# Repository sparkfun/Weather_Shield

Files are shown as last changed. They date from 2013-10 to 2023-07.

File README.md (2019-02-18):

SparkFun Weather Shield
========================

SparkFun Weather Shield (https://www.sparkfun.com/products/13956)  

[*SparkFun Weather Shield (DEV-13956)*](https://www.sparkfun.com/products/13956)

Weather Shield is an Arduino shield that gathers relative humidity, barometric pressure, temperature, light intensity, as well as optional rain, wind direction, and wind speed (using optional [external weather gauges](https://www.sparkfun.com/products/8942)).

Repository Contents
------------------

* **/Firmware** - Example Arduino sketch to demostrate how to read from the various sensors.
* **/Fritzing** - Fritzing Example wiring images
* **/Hardware** - All the Eagle PCB design files (.brd, .sch).
* **/Production** - Test bed files and production panel files

Documentation
--------------
* **[Installing an Arduino Library Guide](https://learn.sparkfun.com/tutorials/installing-an-arduino-library)** - Basic information on how to install an Arduino library.
* **[MPL3115A2 Library](https://github.com/sparkfun/SparkFun_MPL3115A2_Breakout_Arduino_Library)** - MPL3115A2 library required for Weather Shield examples. 
* **[Si7021 Library](https://github.com/sparkfun/SparkFun_Si701_Breakout_Arduino_Library)** - Si7021 humidity sensor library required for Weather Shield examples. 
* **[Hookup Guide](https://learn.sparkfun.com/tutorials/arduino-weather-shield-hookup-guide-v12)** - Basic hookup guide for the Weather Shield v1.2.
* **[SparkFun Fritzing repo](https://github.com/sparkfun/Fritzing_Parts)** - Fritzing diagrams for SparkFun products.
* **[SparkFun 3D Model repo](https://github.com/sparkfun/3D_Models)** - 3D models of SparkFun products. 
* _**[HTU21D Library](https://github.com/sparkfun/SparkFun_HTU21D_Breakout_Arduino_Library)** - The HTU21D humidity sensor was used on DEV-12081 and prior versions of the Weather Shield so if you have an older version you may need this library to run the examples._

Product Versions
----------------
* [DEV-13956](https://www.sparkfun.com/products/13956)- V1.2 w/ Si7021
* _[DEV-12081 (Retired)](https://www.sparkfun.com/products/13956)- HTU21D_

Version History
---------------
* [v1.2](https://github.com/sparkfun/Weather_Shield/releases/tag/v1.2) - Latest Version
* [v1.1](https://github.com/sparkfun/Weather_Shield/releases/tag/v1.1) - Initial Release

License Information
-------------------

This product is _**open source**_! 

Please review the LICENSE.md file for license information. 

If you have any questions or concerns on licensing, please contact techsupport@sparkfun.com.

Distributed as-is; no warranty is given.

- Your friends at SparkFun.

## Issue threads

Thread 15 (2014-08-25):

Instantenous wind speed reported as 0 or NaN

chopsuei3, 2014-08-25:
I set up my Redboard and Weathershield, and attached my weather sensors via the RJ-11 jack.

I compiled and uploaded the code, and receive accurate temperature, humidity and pressure readings.
I also receive accurate wind direction readings.

But the wind speed (instantaneous) returns either 0 or NaN.

Here is the example serial monitor output when spinning the anemometer -

$,winddir=45,windspeedmph=nan,windgustmph=0.0,windgustdir=0,windspdmph_avg2m=0.0,winddir_avg2m=0,windgustmph_10m=0.0,windgustdir_10m=0,humidity=41.9,tempf=78.4,rainin=0.00,dailyrainin=0.00,pressure=100737.25,batt_lvl=4.42,light_lvl=0.30,#

$,winddir=45,windspeedmph=0.0,windgustmph=0.0,windgustdir=0,windspdmph_avg2m=0.0,winddir_avg2m=1,windgustmph_10m=0.0,windgustdir_10m=0,humidity=41.9,tempf=78.5,rainin=0.00,dailyrainin=0.00,pressure=100735.50,batt_lvl=4.42,light_lvl=0.28,#

I commented out lines 335 to 337 to try debugging a bit.
When I do this, the WindSpeed is printed twice, once as 0 and once as the correct speed.

$,winddir=225,windspeedmph=0.0,windgustmph=0.0,windgustdir=0,windspdmph_avg2m=0.9,winddir_avg2m=36,windgustmph_10m=12.1,windgustdir_10m=225,humidity=42.3,tempf=77.7,rainin=0.00,dailyrainin=0.00,pressure=100745.75,batt_lvl=4.42,light_lvl=0.33,#
Loop call:

Windspeed:5.48
Wind clicks:0
calcWeather call:

Windspeed:0.00
Wind clicks:0

$,winddir=225,windspeedmph=0.0,windgustmph=0.0,windgustdir=0,windspdmph_avg2m=1.0,winddir_avg2m=38,windgustmph_10m=12.1,windgustdir_10m=225,humidity=42.3,tempf=77.6,rainin=0.00,dailyrainin=0.00,pressure=100742.25,batt_lvl=4.42,light_lvl=0.30,#
Loop call:

Windspeed:4.53
Wind clicks:0
calcWeather call:

Windspeed:0.00
Wind clicks:0

Further research reveals that get_wind_speed() is called twice, once in the main loop and once within calcWeather().
I added a few debug readings, and I believe the correct WindSpeed is printed within the main loop.
For some reason, the get_wind_speed() called within calcWeather() returns 0.

Am I missing something obvious?

It seems like the problem is related to the averaging of wind speed values over time.

I used the code directly from here.

Please help, thanks.
Let me know if there are more questions.

Thanks!

TechRep, 2015-05-02:
I got the same problem, have you been able to figure out the issue?

nseidle, 2015-09-11:
It looks like javacasm found the error. See https://github.com/sparkfun/Weather_Shield/pull/17/files#diff-0 It requires the change of one line

     //Calc the wind speed and direction every second for 120 second to get 2 minute average
-    float currentSpeed = get_wind_speed();
+    float currentSpeed = windspeedmph;

However, I'm still not seeing windgustmph change. Very odd.

nseidle, 2015-09-11:
Hmm, I think I found it. calcWeather() was zeroing out the values when it shouldn't. This sketch: https://codebender.cc/sketch:116056 should be fixed now. I will update the repo shortly.

Closed 2015-09-11.

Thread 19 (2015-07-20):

Getting wrong data?

thelostscientist, 2015-07-20:
$,winddir=-1,windspeedmph=nan,windgustmph=0.0,windgustdir=0,windspdmph_avg2m=5.7,winddir_avg2m=-1,windgustmph_10m=6.2,windgustdir_10m=-1,humidity=998.0,tempf=-1766.2,rainin=7.78,dailyrainin=7.79,pressure=-999.00,batt_lvl=inf,light_lvl=nan,#

rjp663, 2015-11-01:
I'm seeing the same temperature error (tempf=-1766.2).  The error seems to occur after about 24hours of run time.  Did you ever find the root cause for this issue?

Thanks,
Rick

ClintonKeith, 2015-11-18:
I'm seeing the temperature sensor defaulting to this temperature as well.  Sometimes it happens within an hour of reset, sometimes days later.

amitpatel144, 2016-03-06:
I face this troubling issue too. Is your problem solved or not ? Wait for your reply Mr. thelostscientist.

ClintonKeith, 2016-03-06:
No response here.  So I installed a DHT22 and get the temp/humidity from that now.

amitpatel144, 2016-03-06:
And Sir what about pressure Sensor MPL3115A2? Is it working properly?

ClintonKeith, 2016-03-06:
It’s working.  It doesn’t seem too accurate, but that’s the nature of most inexpensive pressure sensors.

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

amitpatel144, 2016-03-07:
Thanks Clinton Keith Sir, for important suggestion. As per as datasheet MPL3115A2 is high accurate pressure sensor, but I doesn't believed it. I used it but I am not satisfied from it. Many times it’s given -999hPa, wrong data and temperature too. One of my friend suggest again about this sensor.  I was in dilemma that may be my sensor is not working properly .But actually it is the base problem of this sensor.  Nor you and I but also many people faced this problem .The sensor manufacturer said that it’s your connection problem or I2C problem. Same as happen in temperature and humidity sensor HTU21D.

Thanks for suggestion. Now I moved to Bosch Sensortec sensor BME280.

ClintonKeith, 2016-03-07:
Thanks Amit,

Please let us know how the BME280 works out.  I may have to follow your lead.

The data I get from the MPL (plot below), shows noise within the accuracy range from the datasheet, but the overall average disagrees with other sensors in the area.  I might try to install another sensor nearby to compare.

Clint

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

amitpatel144, 2016-03-08:
Thanks for your best wishes. I'll try on BME280 as soon as possible.

ClintonKeith, 2016-03-11:
Just a follow-up on the built in sensor.  It’s worse than I thought.  The three plots show three local weather station barometric sensors.  The bottom one is the mine (the built-in weather shield).  The pressure response is the opposite of the others!  I noticed this as a storm just moved through.  I expected pressure to be dropping.

I’ll bet there is a bug with the example code.

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

amitpatel144, 2016-03-12:
yes ; I agree with you . I think i should need run both sensor at a time. Then I can distinguish better results .
Sir, I think you already watched the comparison result. If not then please watched it.
link: http://wiki.paparazziuav.org/wiki/Baro_comparsion

amitpatel144, 2016-04-07:
Hello Sir, I purchase a new sensor named BME280. Its precision is 1 meter .I got better result then any other pressure sensor. I got a huge difference between reading of MPL3115A2 and BME280. The noise level is low than MPL3115A2. I got many better feedback on BME280. This support I2C and SPI.
I'll attach output soon. Thanks for your best wishes.

amitpatel144, 2016-04-07:
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

nseidle, 2016-06-10:
To address the original problem: a humidity of 998 means the humidity sensor failed to respond over I2C in a timely fashion (ie, not at all). Similary, -999 from the pressure sensor means it failed as well. There is most likely a problem with your I2C bus. If you're using the shield check the solder connection. If you're using a combination of breakout boards double check that the bus has 4.7k pull-up resistors on the SDA/SCL lines. Most of our breakout boards have these pull-ups installed but not all companies include them.

I've touched up the [hook-up tutorial](https://learn.sparkfun.com/tutorials/weather-shield-hookup-guide#example-firmware---basic) to include a new basic sketch. Please give this a try as it will specifically call out an error if I2C communication fails.

@rjp663 I have seen the tempf go negative when I pulled the shield from the board while it was powered up and running, and then re-inserted the shield after a few seconds. I attribute this failure mode to the pressure sensor not getting re-initialized correctly.

I've had a handful of these shields in the field for months at a time without sensors needing to be reset or power cycled. I will run a few-day test over the weekend and re-open the issue.

rjp663, 2016-06-11:
Nathen,

Thanks for your detailed analysis.  Due to the unreliability of the shield I've move my temp and pressure sensors off board utilizing a BME280. The weather shield at this point only provides pull-up resistors for the rain, wind speed and wind direction connections.  I've also rewritten much of the code.

I've spent my free time for this last year playing around with this weather station.  Sooner or later I've got to stop tweaking on it and move on to another project.

Rick

Sent from my iPad

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

amitpatel144, 2016-06-11:
Is anyone got solution of MPL3115A2 sensor on Adruino due board?

aleixq, 2018-04-09:
Sorry to make it alive again but I get correct results using https://github.com/mariocannistra/MPL3115A2 . Running the calibration previously to get the value gives correct results. Run barometer_calibration example to test it (if running this example a lot of time it ends giving -999, let it rest for a while after)

Here I paste snippets of the code that I run giving good values:
```
float barominMb = 0.0;
float city_meters_above_sea = 280.0; // HARDCODED ALTITUDE
void setup(void){
//Configure the pressure sensor
myPressure.setModeStandby();    // <-- this one starts a config sequence
myPressure.setModeBarometer();
myPressure.setOversampleRate(7);
myPressure.enableEventFlags();
myPressure.setModeActive();
myPressure.runCalibration(city_meters_above_sea);
}
...
void loop(){
pressure = myPressure.readPressure();
barominMb = getPressuremb(pressure, city_meters_above_sea);
}
...
float getPressuremb(float pressure, float currentElevation)
{
  float pressure_offset = pressure + myPressure.elevation_offset;

  // output is in Pa
  // 1 kPa = 10 hPa = 1000 Pa
  // 1 hPa = 100 Pascals = 1 mb
  pressure_offset = (pressure_offset / 100) ;   //  ... / 1000 * 10 ;
  return pressure_offset;
}

```

nseidle, 2018-04-18:
Please start a new issue with as much of a description of your issue as possible.

Closed 2016-06-10.

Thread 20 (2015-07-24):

Does it work with arduino YUN?

thelostscientist, 2015-07-24:

nseidle, 2016-06-10:
Yes it should. The Yun uses an ATmega32U4 as the co-processor. See the [schematic](https://www.arduino.cc/en/uploads/Main/arduino-Yun-schematic.pdf) for more information. The shield should plug in and be able to communicate with the 32U4 without issue. However, all our example code is written for the Uno and RedBoard so I'm not sure I can help with code for the Yun.

Closed 2016-06-10.

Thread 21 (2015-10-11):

Example includes don't match library file names

ClintonKeith, 2015-10-11:
When compiling the Weather Shield example, I noticed that the includes:
#include "MPL3115A2.h" //Pressure sensor
#include "HTU21D.h" //Humidity sensor

needed to be changed to
#include "SparkFunMPL3115A2.h" //Pressure sensor
#include "SparkFunHTU21D.h" //Humidity sensor

Not sure which is correct (lib names or includes)

ToniCorinne, 2015-10-13:
Sorry about that! We tried to get all the example code when updating the Arduino libraries for 1.6+. Those have been fixed in commit 6442113715a5fa2c2fe53822eba27b16542d7d89. Thanks for pointing that out.

Closed 2015-10-13.

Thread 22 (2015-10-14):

Memory optimizations

ClintonKeith, 2015-10-14:
I've integrated the weathershield with an Uno and Xbee using SoftSerial to communicate.  Including the Xbee and SoftSerial libraries was a challenge due to the SRAM memory useage of the example sketch.  I cleaned up a number of the memory usage problems and have others to go, but thought I'd raise the issue here for discussion before I create a pull request:
- Use flash memory whenever possible.  Convert all print strings by putting them into the F() macro.
- Reduce averaging array size.  E.g. wind averaging arrays are 120 ints in size.  They can be reduced in size, samples taken less frequently or "averages of averages" can be used.
- Use constants and defines instead of values.  "120", "199", "10" are used repeatedly throughout the code for array and iteration size.  Constants defined at the top would allow more control.

BTW: Really impressed with how quickly this shield, hardware and example came up and ran.  Good job.

ToniCorinne, 2015-10-14:
These all sounds like great improvements. Please do issue a pull request and we'll take a look at it. Even if it doesn't necessarily work for our examples, it's a great record to have out there for other users.

nseidle, 2016-06-10:
Hi ClintonKeith - Yes please! If you get a good sketch put together and would like to share we'd be happy to cross link. I just touched up the [hook-up guide](https://learn.sparkfun.com/tutorials/weather-shield-hookup-guide#example-firmware---basic) and created some additional, more basic sketches to get beginners up and running. If you see places to improve the basic, weather station, or GPS sketches please do so and shoot us a pull request.

If I ever touch-up my weather stations I'll use that moment to circle back and implement some of your suggestions as well. I just can't make changes to the core code without a full setup to test it on.

Closed 2016-06-10.

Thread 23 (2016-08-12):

Error in GPS Example Code for Longitude

bboyho, 2016-08-12:
Customer brought up an error in the SFE Forums [ https://forum.sparkfun.com/viewtopic.php?f=14&t=39246#p176148 ]. GPS example code [ https://github.com/sparkfun/Weather_Shield/blob/master/firmware/Weather_Shield_with_GPS/Weather_Shield_with_GPS.ino ] has an error in the code when printing the variable name with the variable. Instead of saying longitude=, the code says that the latitude is equal to the longitude's value on line 445:

    Serial.print(",lat=");
    Serial.print(gps.location.lat(), 6);
    Serial.print(",lat=");
    Serial.print(gps.location.lng(), 6);

It should probably say:

    Serial.print(",lat=");
    Serial.print(gps.location.lat(), 6);
    Serial.print(",lng=");
    Serial.print(gps.location.lng(), 6);

ToniCorinne, 2016-08-12:
@bboyho if you want to change the code file and submit a pull request, I can get that pulled in.

bboyho, 2016-08-12:
Yup, already on it @ToniCorinne . I had to file the issues first so customers can track down the issues. I have forked it and will send in a pull request with the corrections soon. =)

bboyho, 2016-08-12:
Issue fixed in forked commit => https://github.com/bboyho/Weather_Shield/commit/d09a0d830e3668e70adf77a1f900ca0f23c9663b

ToniCorinne, 2016-08-16:
Fixed - closing the issue.

Closed 2016-08-16.

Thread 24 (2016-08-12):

Error in Weather_Shield_Weather_Station.ino where "windspeedmph" reads "0.0"

bboyho, 2016-08-12:
There have been customers reporting that the variable "_windspeedmph_" is constantly reporting "0.0". This is an error in the code Weather_Shield_Weather_Station.ino [ https://github.com/sparkfun/Weather_Shield/blob/master/firmware/Weather_Shield_Weather_Station/Weather_Shield_Weather_Station.ino ].

Looking at the sequence of code, it appears that whoever originally wrote the code did not update the global variable _windspeedmph_ for the _printWeather()_ function. Line 226 was commented out in _calcWeather()_ because the function _get_wind_speed()_ was already called in the loop function. The value was saved in the local variable called _currentSpeed_ on line 178:

    //Calc the wind speed and direction every second for 120 second to get 2 minute average
    float currentSpeed = get_wind_speed();
    .
    .
    .

By saving the value from _currentSpeed_ to the global variable, the global variable _windspeedmph_ was able to update and display a value other than "0.0":

    //Calc the wind speed and direction every second for 120 second to get 2 minute average
    float currentSpeed = get_wind_speed();
    windspeedmph = currentSpeed;//update global variable for windspeed when using the printWeather() function
    .
    .
    .

**Verifying _windspeedmph_**

You can verify that the value is correct by uncommenting out lines 356-358 and removing "/*" and "*/":

    /* Serial.println();
    Serial.print("Windspeed:");
    Serial.println(windSpeed);*/

Keep in mind that the the value printed in _calcWeather()_ outputs to the nearest hundredth while _printWeather()_ outputs to the nearest tenth. This is due to the way _serial.print()_ is called [ https://www.arduino.cc/en/Serial/Print ] . The default has the Arduino print to two decimal places. In _printWeather()_, the code specifies printing to the one decimal place.

bboyho, 2016-08-12:
Issue fixed in forked commit => https://github.com/bboyho/Weather_Shield/commit/d09a0d830e3668e70adf77a1f900ca0f23c9663b

ToniCorinne, 2016-08-16:
Fixed - closing the issue.

Closed 2016-08-16.

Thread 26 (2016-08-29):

v12 checklist issues

ericorosel, 2016-08-29:
(1) Per the standard, it would be nice if the "STAT1" and "STAT2" nets had a bend in them so that the flag could come straight out from the net while reading horizontally.

(2) Most parts have no PROD_ID

(3) The design loaded with an old DRC, and running the a new DRC results in errors

(4) There are air-wires in the design

(5) BRD contains Proportional text

JoelEB, 2016-09-27:
1) Adding bends for flags
2) Updated all parts to latest and added PROD_IDs to parts without.
3) Check board against newest DRC
4) Air-wires have been fixed
5) Text on BRD and SCH has been changed to vector.

Closed 2016-09-27.

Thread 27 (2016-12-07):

Double Check v12

edspark, 2016-12-07:
1) Are any jumpers labeled clearly by their function and possible settings? [NO]
comment: The Jumper for the Pressure Interrupt is labeled nicely on the board, but not on the schematic.

2) Is the board dimension outline correct thickness? (0.008 inch) [NO]
comment: The top edge dimension lines are .01

3) Does it pass SparkFun DRC? [NO]
comment: No but we're cool. Same restrict issues as the Photon Weather Shield.

4) Does it pass DRC with top/bottom keepout layers on? [NO]
comment: It's cool.

5) Do all packages have NAME and VALUE? [NO]
comment: Nope, it's fine.

6) Is the polarity label outside of the package for visibility after part population? [NO]
comment: No but it's cool.

7) The labels on Diodes D8, D10, and D5 are missing.

Closed 2016-12-09.

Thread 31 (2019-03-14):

Weather shield not working on Arduino Uno WIFI Rev 2

skuske, 2019-03-14:
All examples work fine on an Arduino Uno, but **they are not working** on an Arduino Uno WIFI Rev 2 - a lot of errors are produced when I try to upload any of the examples:

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

tkeifer, 2019-05-03:
Any updates on this? I'm running into the same issues. (negative values on Temperature/Pressure and can't include the Si7021 library without running into the same compile errors above)

Example code from the Sparkfun MPL3115A2 library
`Pressure(Pa): -31265 Temp(f): -1766.20
Pressure(Pa): -31204 Temp(f): -1766.20
Pressure(Pa): -31148 Temp(f): -1766.20
Pressure(Pa): -31333 Temp(f): -1766.20
Pressure(Pa): -31325 Temp(f): -1766.20
Pressure(Pa): -31434 Temp(f): -1766.20`

This is the 3rd WIFI companion board I've used with no luck...

skuske, 2019-05-08:
I am wondering if anybody of sparkfun monitors the issues... I doubt they do. Bad service.

tkeifer, 2019-05-08:
I've had a little better luck over at their forums: https://forum.sparkfun.com/

...but yeah, it seems like the way they have this shield setup it only is really designed to work with their Photon boards. Pretty disappointed with them as well.

santaimpersonator, 2019-12-31:
@skuske Sorry, we have a lot of repos that we curate; not including our forums, product pages, hookup guides, and etc.

I am marking this a duplicate and closing this issue since it isn't related to the hardware and there is another issue already file for the library causing the compilation issue (see https://github.com/sparkfun/SparkFun_Si701_Breakout_Arduino_Library/issues/4). This is was my response regarding this issue:

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

Closed 2019-12-31.

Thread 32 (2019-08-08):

Commented line #234 prevents working with GPS in Weather_Shield_with_GPS_V12.ino

wittend, 2019-08-08:
The fact that line #234 is commented out at the end of loop() prevents firmwareWeather_Shield_with_GPS_V12.ino from reading GPS if attached.  This problem is present in both the repo code and the code embedded in the tutorial page "Arduino Weather Shield Hookup Guide V12".

Uncommenting this line seems to fix things, at least with the specified GPS.

santaimpersonator, 2024-02-29:
Closing, as this is no longer relavent to the new code implementation

Closed 2024-02-29.

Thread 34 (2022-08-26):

Getting wrong readings

vdenduluri, 2022-08-26:
Hi,

I connected the [weather shield](https://www.sparkfun.com/products/13956) to [sparkfun redboard plus](https://www.sparkfun.com/products/18158) and ran the example program "Weather_Shield_Basic_V12". I am getting incorrect readings.

Is there something that I should do first before executing the program or something wrong with hardware? Anyhelp would be appreciated.

Humidity = -5.81%, temp_h = -51.85F, Pressure = -999.00Pa, temp_p = -1766.20F, light_lvl = 2.14V, VinPin = 12.08V
Humidity = -5.81%, temp_h = -51.85F, Pressure = -999.00Pa, temp_p = -1766.20F, light_lvl = 2.19V, VinPin = 11.91V
Humidity = -5.81%, temp_h = -51.85F, Pressure = -999.00Pa, temp_p = -1766.20F, light_lvl = 2.19V, VinPin = 12.08V
Humidity = -5.81%, temp_h = -51.85F, Pressure = -999.00Pa, temp_p = -1766.20F, light_lvl = 2.08V, VinPin = 12.90V

Thanks.

santaimpersonator, 2023-06-22:
Based upon the VinPin reading, make sure you are connecting an appropriate backup battery as defined in the schematic:
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

_If you are still running into issues, please use our [forum](https://forum.sparkfun.com/) to submit a post for some [technical assistance](https://www.sparkfun.com/technical_assistance)._

santaimpersonator, 2024-02-29:
No response; closing issue.

Closed 2024-02-29.

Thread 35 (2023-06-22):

Feature Request: 3.3V compatibility

santaimpersonator, 2023-06-22:
Just a future consideration for the shield. Utilize the IOREF/AREF pins to make the shield compatible with our 3.3V boards:

- [RedBoard Artemis](https://www.sparkfun.com/products/15444)
- [IoT RedBoard - ESP32](https://www.sparkfun.com/products/19177)
- [RedBoard Turbo -  SAMD21](https://www.sparkfun.com/products/14812)

Currently, the windvane direction is pulled up to 5V. This causes issues when a 3.3V ADC tries to read that pin *(reading is maxed out)*. *(\*I didn't look into the annemometer and rain gauge pins, but I assume that utilizing IOREF would be optimal for those pins as well.)*

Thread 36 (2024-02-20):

Compiling Issue (variable is not a type)

alsim95, 2024-02-20:
Hi everyone, I just bought recently a pair of weather shields to build weather stations and I wanted to try them today. I have installed the necessary libraries (Si7021, MPL3115A2 and Weather Meter Kit) but when I try to either simply verify or upload the Weather Shield firmware example, I get a compiling issue which says basically the following :

error: 'Weather' does not name a type
error: 'myHumidity' was not declared in this scope

It's depending of the line 26 of the .ino code, which is :

Weather myHumidity;//Create an instance of the humidity sensor

It seems pretty strange as all libraries are properly installed, and I did not change any single line of the code. I also didn't see any trace of that issue anywhere of the web, so I don't really know what to do. Can someone help me with that please ? Thanks and have a nice day !

PaulZC, 2024-02-20:
Hi @alsim95 ,

Please check you still have these lines at the start of your code:

```
#include "SparkFunMPL3115A2.h" //Pressure sensor - Search "SparkFun MPL3115" and install from Library Manager
#include "SparkFun_Si7021_Breakout_Library.h" //Humidity sensor - Search "SparkFun Si7021" and install from Library Manager
```

Best wishes,
Paul

alsim95, 2024-02-20:
Hi @PaulZC thank you for your answer. Indeed, I still have these lines on top of the code. I found some kind of solution actually. The problem seems to be the module "Weather" which is called but doesn't exist in any of these libraries. I tried replacing it with the module named "SI7021" as described in that library and it is compiling now. But after uploading the sketch into the Arduino I don't seem to get any proper values. Here is an example :

Humidity = 0.00%, temp_h = -52.33F, Pressure = -999.00Pa, temp_p = -1766.20F, light_lvl = 0.83V, VinPin = 4.46V

Is there something wront with the board maybe ? It seems to be powered on properly as the blue led on the shield is flashing, and I feel like I soldered the headers correctly.

PaulZC, 2024-02-20:
Hi @alsim95 ,

Ah, I am sorry. It looks like the example code has been partially updated, but not fully.

I am looking at the hook-up guide: https://learn.sparkfun.com/tutorials/arduino-weather-shield-hookup-guide-v12#example-firmware---basic

If you install and include the SparkFun_Weather_Meter_Kit_Arduino_Library, all should be well.

```
#include "SparkFun_Weather_Meter_Kit_Arduino_Library.h"  //Weather meter kit - Search "SparkFun Weather Meter" and install from Library Manager
```

Please let me know if this fixes your issue.

Best wsihes,
Paul

alsim95, 2024-02-20:
I tried using that sketch (Weather_Shield_Basic_V12.ino as found here on Github) and just added the line you mentionned, however it doesn't change anything, I still get that compiling error...

PaulZC, 2024-02-20:
OK - thank you. I am sorry. I have let my colleague know about the issue. We will get the example code updated soon.

Best wishes,
Paul

alsim95, 2024-02-20:
Thanks ! Also, for your information, when I change the module "Weather" to "SI7021", the first time I compile and upload the sketch, I get the following message :

In file included from c:\Users\alegrand\Documents\Arduino\libraries\SparkFun_MPL3115A2_Altitude_and_Pressure_Sensor_Breakout\src\SparkFunMPL3115A2.cpp:36:0:
C:\Users\alegrand\AppData\Local\Arduino15\packages\arduino\hardware\avr\1.8.6\libraries\Wire\src/Wire.h: In member function 'float MPL3115A2::readAltitude()':
C:\Users\alegrand\AppData\Local\Arduino15\packages\arduino\hardware\avr\1.8.6\libraries\Wire\src/Wire.h:68:13: note: candidate 1: uint8_t TwoWire::requestFrom(int, int)
     uint8_t requestFrom(int, int);
             ^~~~~~~~~~~
C:\Users\alegrand\AppData\Local\Arduino15\packages\arduino\hardware\avr\1.8.6\libraries\Wire\src/Wire.h:65:13: note: candidate 2: uint8_t TwoWire::requestFrom(uint8_t, uint8_t)
     uint8_t requestFrom(uint8_t, uint8_t);
             ^~~~~~~~~~~
C:\Users\alegrand\AppData\Local\Arduino15\packages\arduino\hardware\avr\1.8.6\libraries\Wire\src/Wire.h: In member function 'float MPL3115A2::readPressure()':
C:\Users\alegrand\AppData\Local\Arduino15\packages\arduino\hardware\avr\1.8.6\libraries\Wire\src/Wire.h:68:13: note: candidate 1: uint8_t TwoWire::requestFrom(int, int)
     uint8_t requestFrom(int, int);
             ^~~~~~~~~~~
C:\Users\alegrand\AppData\Local\Arduino15\packages\arduino\hardware\avr\1.8.6\libraries\Wire\src/Wire.h:65:13: note: candidate 2: uint8_t TwoWire::requestFrom(uint8_t, uint8_t)
     uint8_t requestFrom(uint8_t, uint8_t);
             ^~~~~~~~~~~
C:\Users\alegrand\AppData\Local\Arduino15\packages\arduino\hardware\avr\1.8.6\libraries\Wire\src/Wire.h: In member function 'float MPL3115A2::readTemp()':
C:\Users\alegrand\AppData\Local\Arduino15\packages\arduino\hardware\avr\1.8.6\libraries\Wire\src/Wire.h:68:13: note: candidate 1: uint8_t TwoWire::requestFrom(int, int)
     uint8_t requestFrom(int, int);
             ^~~~~~~~~~~
C:\Users\alegrand\AppData\Local\Arduino15\packages\arduino\hardware\avr\1.8.6\libraries\Wire\src/Wire.h:65:13: note: candidate 2: uint8_t TwoWire::requestFrom(uint8_t, uint8_t)
     uint8_t requestFrom(uint8_t, uint8_t);
             ^~~~~~~~~~~
C:\Users\alegrand\AppData\Local\Arduino15\packages\arduino\hardware\avr\1.8.6\libraries\Wire\src/Wire.h: In member function 'byte MPL3115A2::IIC_Read(byte)':
C:\Users\alegrand\AppData\Local\Arduino15\packages\arduino\hardware\avr\1.8.6\libraries\Wire\src/Wire.h:68:13: note: candidate 1: uint8_t TwoWire::requestFrom(int, int)
     uint8_t requestFrom(int, int);
             ^~~~~~~~~~~
C:\Users\alegrand\AppData\Local\Arduino15\packages\arduino\hardware\avr\1.8.6\libraries\Wire\src/Wire.h:65:13: note: candidate 2: uint8_t TwoWire::requestFrom(uint8_t, uint8_t)
     uint8_t requestFrom(uint8_t, uint8_t);
             ^~~~~~~~~~~

But it doesn't abort the compiling, it is actually working and uploading afterwards. I must admit that my understanding of the variables declarations and types is not perfect but do you think that could explain why I don't get any correct values ?

santaimpersonator, 2024-02-29:
So it looks like the Si7021 Arduino library was recently updated: https://github.com/sparkfun/SparkFun_Si7021_Arduino_Library/commits/main/

The example code in the hookup guide and this repo were written for the previous version. Try rolling back the Arduino library to the v1.0.5 release:
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

santaimpersonator, 2024-02-29:
Due to the new I2C implentation in the latest release of the [Si7021 library *(v2.0.0)*](https://github.com/sparkfun/SparkFun_Si7021_Arduino_Library/releases/tag/v2.0.0), care must be taken in how the all libraries are initialized and linked in the example code.

When linking the libraries, the Wire library must be linked between the Si7021 and MPL3115A2 libraries:

- Due to the new release, the Si7021 library *(v2.0.0)* must be linked before the Wire library
- As previously utilized, the MPL3115A2 library *(v1.2.4)* must be linked after the Wire library

```cpp
#include "SparkFun_Si7021_Breakout_Library.h"  //Humidity sensor - http://librarymanager/All#SparkFun_Si7021
#include <Wire.h>               //I2C needed for sensors
#include "SparkFunMPL3115A2.h"  //Pressure sensor - //http://librarymanager/All#SparkFun_MPL3115A2
```

When intializing the sensors, the I2C port must be initialized before the humidity sensor. Additionally, the pressure sensor can only be initialized after the humidity sensor:

```cpp
//Configure the humidity sensor
Wire.begin();

while (myHumidity.begin() == false) {
  Serial.println("Sensor not found. Please check wiring. Freezing...");
  while (true)
    ;
}
myHumidity.setResolution(0);  // RH 12-bit, Temp 14-bit (Default)
myHumidity.heaterOff();       // Turn internal heater off
// myHumidity.setHeaterCurrent(0b0000); // Set heater to min 3.09mA (Default)

//Configure the pressure sensor
myPressure.begin();               // Get sensor online
myPressure.setModeBarometer();    // Measure pressure in Pascals from 20 to 110 kPa
myPressure.setOversampleRate(7);  // Set Oversample to the recommended 128
myPressure.enableEventFlags();    // Enable all three pressure and temp event flags
```

---
**Note:** *These, are in addition to how the humidity sensor is instantiated (as mentioned previously):*
```cpp
SI7021 myHumidity;     //Create an instance of the humidity sensor
```
---

This is how the [`Weather_Shield_Basic_V12.ino`](https://github.com/sparkfun/Weather_Shield/blob/master/Firmware/Weather_Shield_Basic_V12/Weather_Shield_Basic_V12.ino) example code would be updated for the current I2C implementations inside of the Si7021 and MPL3115A2 Arduino libraries:

```cpp
/*
  Weather Shield Example
  By: Nathan Seidle
  SparkFun Electronics
  Date: June 10th, 2016
  License: This code is public domain but you buy me a beer if you use this and we meet someday (Beerware license).

  This example prints the current humidity, air pressure, temperature and light levels.

  The weather shield is capable of a lot. Be sure to checkout the other more advanced examples for creating
  your own weather station.

  Updated by Joel Bartlett
  03/02/2017
  Removed HTU21D code and replaced with Si7021

  Updated by Wes F
  02/29/2024
  Accounted for updated Si7021 library release

*/

#include "SparkFun_Si7021_Breakout_Library.h"  //Humidity sensor - http://librarymanager/All#SparkFun_Si7021
#include <Wire.h>               //I2C needed for sensors
#include "SparkFunMPL3115A2.h"  //Pressure sensor - //http://librarymanager/All#SparkFun_MPL3115A2

MPL3115A2 myPressure;  //Create an instance of the pressure sensor
SI7021 myHumidity;     //Create an instance of the humidity sensor

//Hardware pin definitions
//-=-=-=-=-=-=-=-=-=-=-=-=-=-=-=-=-=-=-=-=-=-=-=-=-=-=-=-=
const byte STAT_BLUE = 7;
const byte STAT_GREEN = 8;

const byte REFERENCE_3V3 = A3;
const byte LIGHT = A1;
const byte BATT = A2;

//Global Variables
//-=-=-=-=-=-=-=-=-=-=-=-=-=-=-=-=-=-=-=-=-=-=-=-=-=-=-=-=
long lastSecond;  //The millis counter to see when a second rolls by

void setup() {
  Serial.begin(115200);
  Serial.println("Weather Shield Example");

  pinMode(STAT_BLUE, OUTPUT);   //Status LED Blue
  pinMode(STAT_GREEN, OUTPUT);  //Status LED Green

  pinMode(REFERENCE_3V3, INPUT);
  pinMode(LIGHT, INPUT);

  //Configure the humidity sensor
  Wire.begin();

  while (myHumidity.begin() == false) {
    Serial.println("Sensor not found. Please check wiring. Freezing...");
    while (true)
      ;
  }
  myHumidity.setResolution(0);  // RH 12-bit, Temp 14-bit (Default)
  myHumidity.heaterOff();       // Turn internal heater off
  // myHumidity.setHeaterCurrent(0b0000); // Set heater to min 3.09mA (Default)

  //Configure the pressure sensor
  myPressure.begin();               // Get sensor online
  myPressure.setModeBarometer();    // Measure pressure in Pascals from 20 to 110 kPa
  myPressure.setOversampleRate(7);  // Set Oversample to the recommended 128
  myPressure.enableEventFlags();    // Enable all three pressure and temp event flags

  lastSecond = millis();

  Serial.println("Weather Shield online!");
}

void loop() {
  //Print readings every second
  if (millis() - lastSecond >= 1000) {
    digitalWrite(STAT_BLUE, HIGH);  //Blink stat LED

    lastSecond += 1000;
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
alsim95, 2024-03-13:
Hi everyone, sorry for coming back to you this late. I had sorted out by myself and the weather shield is woring properly for the moment. However, I am now trying to send the data from the shield (and the meter kit as well) to another Arduino through a nRF24L01 with the Mirf library but I am getting some new issues while compiling. It sounds like some sort of compatibility issue, because as soon as I remove either the Mirf library or the Si7021/MPL3115A2 libraries, then it is compiling properly.

Does any of you have an idea of why this happens ? Is there maybe another library I could use with the nRF24L01 module ? Thanks in advance  !

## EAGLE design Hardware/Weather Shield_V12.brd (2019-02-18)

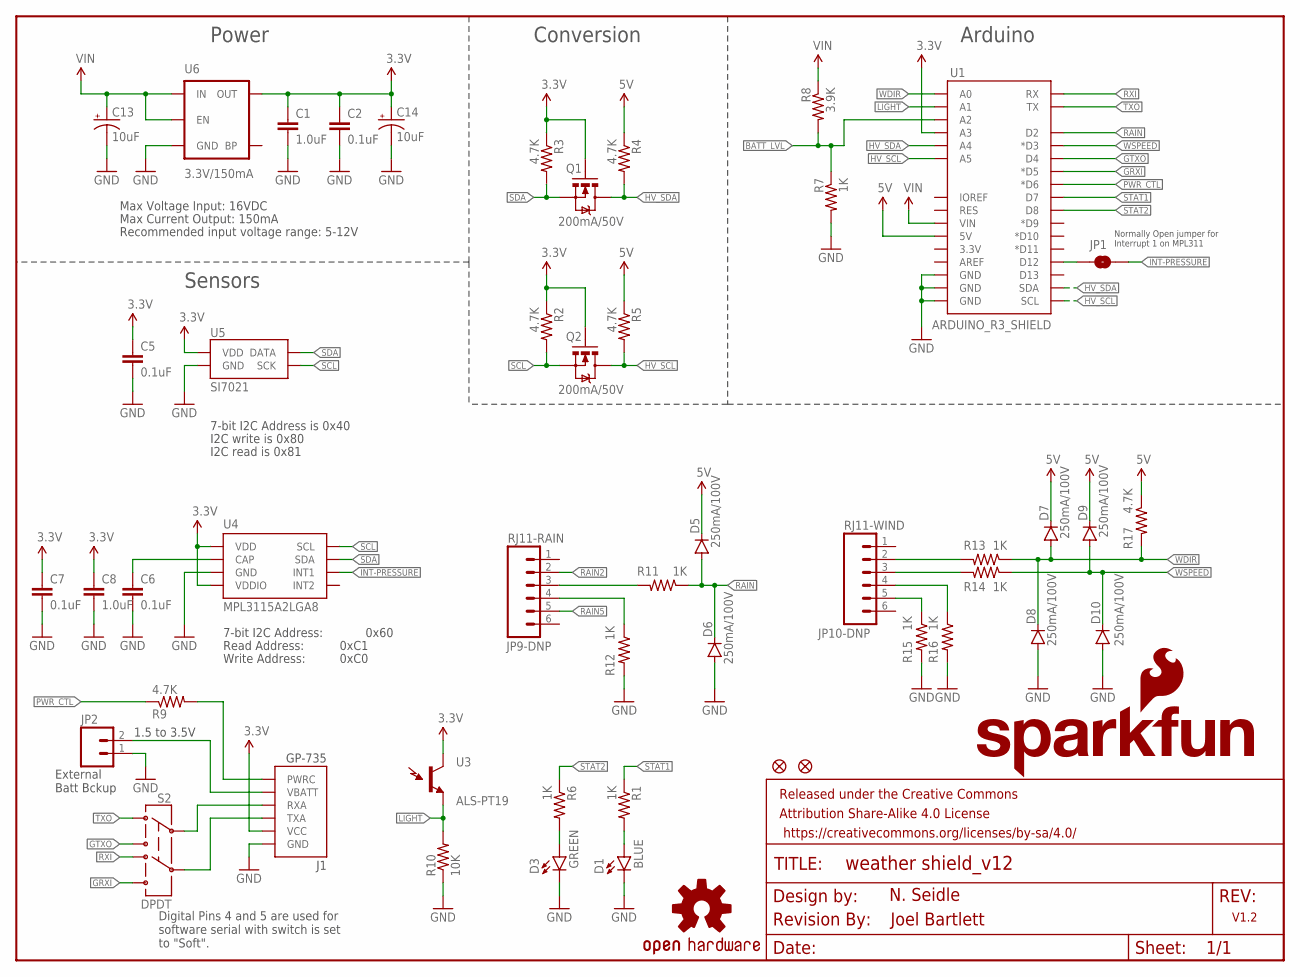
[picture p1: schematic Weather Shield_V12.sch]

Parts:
C1, C8: 1.0uF; 0603-CAP
C2, C5, C6, C7: 0.1uF; 0603-CAP
C13, C14: 10uF; EIA3216
D1: BLUE; LED-0603
D3: GREEN; LED-0603
D5, D6, D7, D8, D9, D10: 250mA/100V; SOD-323
FD1, FD2: FIDUCIAL1X2; FIDUCIAL-1X2
FRAME1: FRAME-LETTER; CREATIVE_COMMONS
J1: GP-735; GP-635T
JP1: JUMPER-PAD-2-NO; PAD-JUMPER-2-NO_NO_SILK
JP2: External Batt Bckup; 1X02
JP9-DNP: RJ11-RAIN; RJ11-6
JP10-DNP: RJ11-WIND; RJ11-6
LOGO1: OSHW-LOGOM; OSHW-LOGO-M
LOGO2: SFE_LOGO_NAME_FLAME.1_INCH; SFE_LOGO_NAME_FLAME_.1
Q1, Q2: 200mA/50V; SOT23-3
R1, R6, R7, R11, R12, R13, R14, R15, R16: 1K; 0603-RES
R2, R3, R4, R5, R9, R17: 4.7K; 0603-RES
R8: 3.9K; 0603
R10: 10K; 0603-RES
S2: DPDT; AYZ0202
U1: ARDUINO_R3_SHIELD; UNO_R3_SHIELD
U3: ALS-PT19
U4: MPL3115A2LGA8; LGA8
U5: SI7021
U6: 3.3V/150mA; SOT23-5
U$2: REVISION

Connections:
3.3V: C1.1, C2.1, C5.1, C7.1, C8.1, C14.A (+), J1.2 (VCC), Q1.1 (G), Q2.1 (G), R2.1, R3.1, U1.A3, U3.C (C1), U4.1 (VDD), U4.4 (VDDIO), U5.VDD, U6.5 (OUT)
3V_PWR_CTL: J1.6 (PWRC), R9.2
5V: D5.C, D7.C, D9.C, R4.1, R5.1, R17.1, U1.5V
BATT_LVL: R7.1, R8.2, U1.A2
GND: C1.2, C2.2, C5.2, C6.2, C7.2, C8.2, C13.C (-), C14.C (-), D1.C, D3.C, D6.A, D8.A, D10.A, J1.1 (GND), JP2.1, R7.2, R10.1, R12.2, R15.2, R16.2, U1.GND@0 (GND), U1.GND@1 (GND), U1.GND@2 (GND), U4.3 (GND), U5.GND, U6.2 (GND)
GPS-RX: J1.4 (RXA), S2.2
GPS-TX: J1.3 (TXA), S2.5
GRXI: S2.6, U1.D5 (*D5)
GTXO: S2.3, U1.D4
HV_SCL: Q2.3 (D), R5.2, U1.A5, U1.SCL
HV_SDA: Q1.3 (D), R4.2, U1.A4, U1.SDA
INT-PRESSURE: JP1.2, U4.6 (INT1)
LIGHT: R10.2, U1.A1, U3.E (E1)
unnamed: JP10-DNP.3, R14.2
unnamed: JP10-DNP.2, R13.2
unnamed: D1.A, R1.2
unnamed: JP9-DNP.3, R11.2
unnamed: C6.1, U4.2 (CAP)
unnamed: JP1.1, U1.D12
unnamed: D3.A, R6.2
unnamed: JP9-DNP.4, R12.1
unnamed: JP10-DNP.5, R15.1
unnamed: JP10-DNP.4, R16.1
PWR_CTL: R9.1, U1.D6 (*D6)
RAIN: D5.A, D6.C, R11.1, U1.D2
RAIN2: JP9-DNP.2
RAIN5: JP9-DNP.5
RXI: S2.4, U1.RX
SCL: Q2.2 (S), R2.2, U4.8 (SCL), U5.SCK
SDA: Q1.2 (S), R3.2, U4.7 (SDA), U5.DATA
STAT1: R1.1, U1.D7
STAT2: R6.1, U1.D8
TXO: S2.1, U1.TX
VIN: C13.A (+), R8.1, U1.VIN, U6.1 (IN), U6.3 (EN)
V_BATT: J1.5 (VBATT), JP2.2
WDIR: D7.A, D8.C, R13.1, R17.2, U1.A0
WSPEED: D9.A, D10.C, R14.1, U1.D3 (*D3)

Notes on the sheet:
Max Voltage Input: 16VDC
Max Current Output: 150mA
N. Seidle
Read Address:
Write Address:
7-bit I2C Address:
0x60
0xC1
0xC0
7-bit I2C Address is 0x40
I2C write is 0x80
I2C read is 0x81
1.5 to 3.5V
External Batt Bckup
Sensors
Power
Conversion
Arduino
V1.2
Digital Pins 4 and 5 are used for software serial with switch is set to "Soft".
Joel Bartlett
Recommended input voltage range: 5-12V
Normally Open jumper for Interrupt 1 on MPL311

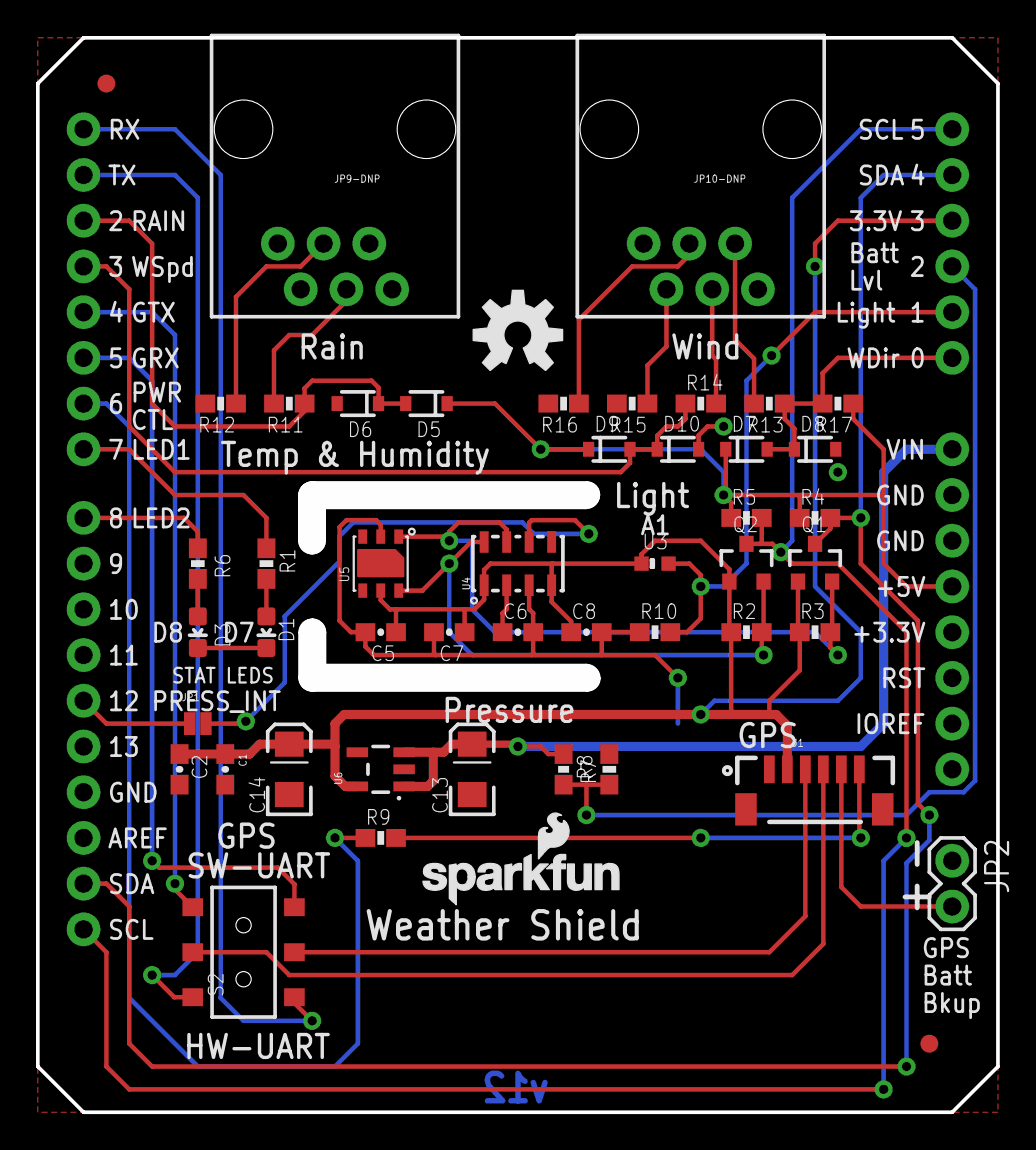
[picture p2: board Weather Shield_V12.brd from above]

Board: 2 copper layers, 53.3 x 59.7 mm, 52 parts (0 on the bottom side), 35 nets.

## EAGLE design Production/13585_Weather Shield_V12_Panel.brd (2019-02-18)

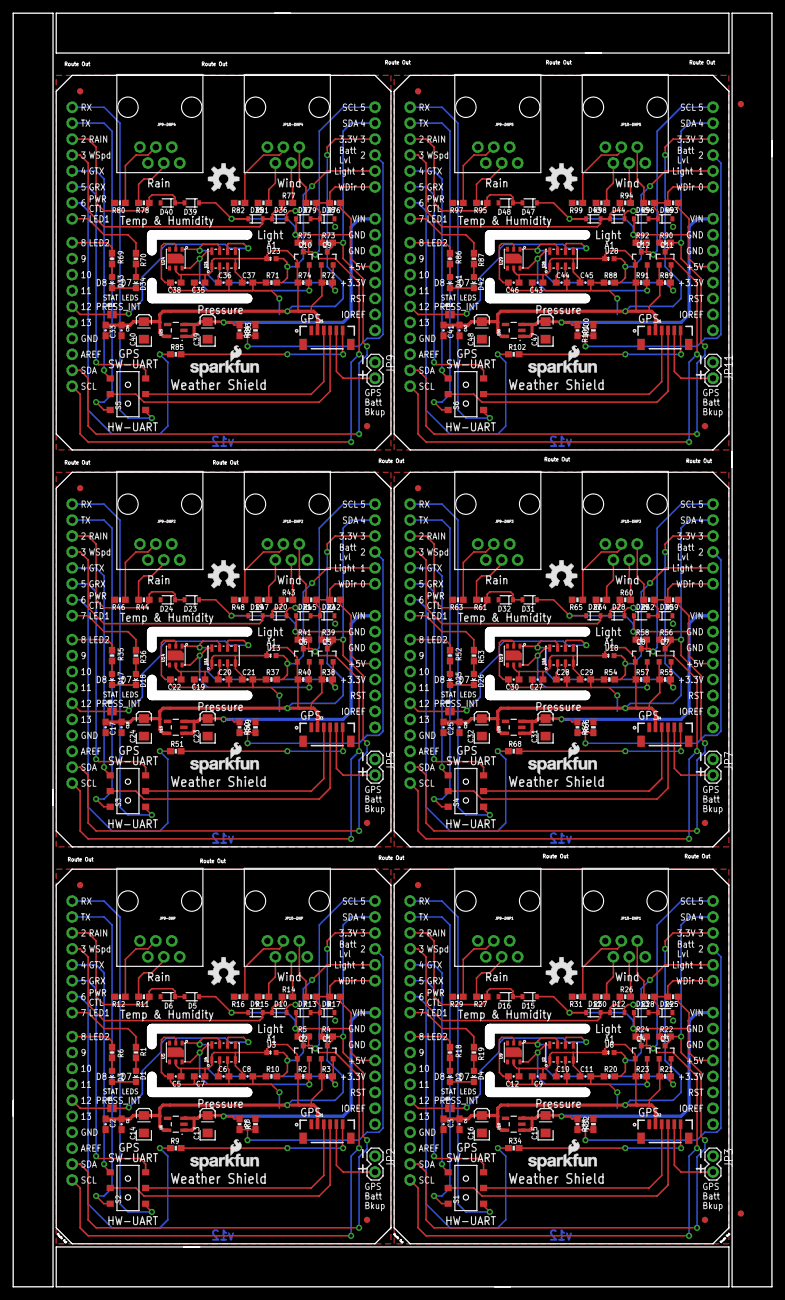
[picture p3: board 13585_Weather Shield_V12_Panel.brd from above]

Board: 2 copper layers, 120.9 x 202.9 mm, 302 parts (0 on the bottom side), 210 nets.

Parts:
C1, C4, C8, C11, C18, C21, C26, C29, C34, C37, C42, C45: 1.0uF; 0603-CAP
C2, C3, C5, C6, C7, C9, C10, C12, C17, C19, C20, C22, C25, C27, C28, C30, C33, C35, C36, C38, C41, C43, C44, C46: 0.1uF; 0603-CAP
C13, C14, C15, C16, C23, C24, C31, C32, C39, C40, C47, C48: 10uF; EIA3216
D1, D4, D18, D26, D34, D42: BLUE; LED-0603
D2, D3, D17, D25, D33, D41: GREEN; LED-0603
D5, D6, D7, D8, D9, D10, D11, D12, D13, D14, D15, D16, D19, D20, D21, D22, D23, D24, D27, D28, D29, D30, D31, D32, D35, D36, D37, D38, D39, D40, D43, D44, D45, D46, D47, D48: 250mA/100V; SOD-323
E$7, E$8: FIDUCIAL-1X2
FD1, FD2, FD3, FD4, FD5, FD6, FD7, FD8, FD9, FD10, FD11, FD12: FIDUCIAL1X2; FIDUCIAL-1X2
J1, J2, J3, J4, J5, J6: GP-735; GP-635T
JP1, JP4, JP6, JP8, JP10, JP12: PAD-JUMPER-2-NO_NO_SILK
JP2, JP3, JP5, JP7, JP9, JP11: External Batt Bckup; 1X02
JP9-DNP, JP9-DNP1, JP9-DNP2, JP9-DNP3, JP9-DNP4, JP9-DNP5: RJ11-RAIN; RJ11-6
JP10-DNP, JP10-DNP1, JP10-DNP2, JP10-DNP3, JP10-DNP4, JP10-DNP5: RJ11-WIND; RJ11-6
LOGO1, LOGO4, LOGO6, LOGO8, LOGO10, LOGO12: OSHW-LOGOM; OSHW-LOGO-M
LOGO2, LOGO3, LOGO5, LOGO7, LOGO9, LOGO11: SFE_LOGO_NAME_FLAME.1_INCH; SFE_LOGO_NAME_FLAME_.1
Q1, Q2, Q3, Q4, Q5, Q6, Q7, Q8, Q9, Q10, Q11, Q12: 200mA/50V; SOT23-3
R1, R6, R7, R11, R12, R13, R14, R15, R16, R18, R19, R26, R27, R28, R29, R30, R31, R32, R35, R36, R43, R44, R45, R46, R47, R48, R49, R52, R53, R60, R61, R62, R63, R64, R65, R66, R69, R70, R77, R78, R79, R80, R81, R82, R83, R86, R87, R94, R95, R96, R97, R98, R99, R100: 1K; 0603-RES
R2, R3, R4, R5, R9, R17, R21, R22, R23, R24, R25, R34, R38, R39, R40, R41, R42, R51, R55, R56, R57, R58, R59, R68, R72, R73, R74, R75, R76, R85, R89, R90, R91, R92, R93, R102: 4.7K; 0603-RES
R8, R33, R50, R67, R84, R101: 3.9K; 0603
R10, R20, R37, R54, R71, R88: 10K; 0603-RES
S1, S2, S3, S4, S5, S6: DPDT; AYZ0202
U1, U7, U12, U17, U22, U27: ARDUINO_R3_SHIELD; UNO_R3_SHIELD
U2, U4, U11, U16, U21, U26: MPL3115A2LGA8; LGA8
U3, U8, U13, U18, U23, U28: ALS-PT19
U5, U9, U14, U19, U24, U29: SI7021
U6, U10, U15, U20, U25, U30: 3.3V/150mA; SOT23-5

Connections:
3.3V: C1.1, C2.1, C5.1, C7.1, C8.1, C14.A, J1.2, Q1.1, Q2.1, R2.1, R3.1, U1.A3, U3.C, U4.1, U4.4, U5.VDD, U6.5
3.3V1: C3.1, C4.1, C9.1, C11.1, C12.1, C16.A, J2.2, Q3.1, Q4.1, R21.1, R23.1, U2.1, U2.4, U7.A3, U8.C, U9.VDD, U10.5
3.3V2: C17.1, C18.1, C19.1, C21.1, C22.1, C24.A, J3.2, Q5.1, Q6.1, R38.1, R40.1, U11.1, U11.4, U12.A3, U13.C, U14.VDD, U15.5
3.3V3: C25.1, C26.1, C27.1, C29.1, C30.1, C32.A, J4.2, Q7.1, Q8.1, R55.1, R57.1, U16.1, U16.4, U17.A3, U18.C, U19.VDD, U20.5
3.3V4: C33.1, C34.1, C35.1, C37.1, C38.1, C40.A, J5.2, Q9.1, Q10.1, R72.1, R74.1, U21.1, U21.4, U22.A3, U23.C, U24.VDD, U25.5
3.3V5: C41.1, C42.1, C43.1, C45.1, C46.1, C48.A, J6.2, Q11.1, Q12.1, R89.1, R91.1, U26.1, U26.4, U27.A3, U28.C, U29.VDD, U30.5
3V_PWR_CTL: J1.6, R9.2
3V_PWR_CTL1: J2.6, R34.2
3V_PWR_CTL2: J3.6, R51.2
3V_PWR_CTL3: J4.6, R68.2
3V_PWR_CTL4: J5.6, R85.2
3V_PWR_CTL5: J6.6, R102.2
5V: D5.C, D7.C, D9.C, R4.1, R5.1, R17.1, U1.5V
5V1: D11.C, D13.C, D15.C, R22.1, R24.1, R25.1, U7.5V
5V2: D19.C, D21.C, D23.C, R39.1, R41.1, R42.1, U12.5V
5V3: D27.C, D29.C, D31.C, R56.1, R58.1, R59.1, U17.5V
5V4: D35.C, D37.C, D39.C, R73.1, R75.1, R76.1, U22.5V
5V5: D43.C, D45.C, D47.C, R90.1, R92.1, R93.1, U27.5V
BATT_LVL: R7.1, R8.2, U1.A2
BATT_LVL1: R32.1, R33.2, U7.A2
BATT_LVL2: R49.1, R50.2, U12.A2
BATT_LVL3: R66.1, R67.2, U17.A2
BATT_LVL4: R83.1, R84.2, U22.A2
BATT_LVL5: R100.1, R101.2, U27.A2
GND: C1.2, C2.2, C5.2, C6.2, C7.2, C8.2, C13.C, C14.C, D1.C, D3.C, D6.A, D8.A, D10.A, J1.1, JP2.1, R7.2, R10.1, R12.2, R15.2, R16.2, U1.GND@0, U1.GND@1, U1.GND@2, U4.3, U5.GND, U6.2
GND1: C3.2, C4.2, C9.2, C10.2, C11.2, C12.2, C15.C, C16.C, D2.C, D4.C, D12.A, D14.A, D16.A, J2.1, JP3.1, R20.1, R29.2, R30.2, R31.2, R32.2, U2.3, U7.GND@0, U7.GND@1, U7.GND@2, U9.GND, U10.2
GND2: C17.2, C18.2, C19.2, C20.2, C21.2, C22.2, C23.C, C24.C, D17.C, D18.C, D20.A, D22.A, D24.A, J3.1, JP5.1, R37.1, R46.2, R47.2, R48.2, R49.2, U11.3, U12.GND@0, U12.GND@1, U12.GND@2, U14.GND, U15.2
GND3: C25.2, C26.2, C27.2, C28.2, C29.2, C30.2, C31.C, C32.C, D25.C, D26.C, D28.A, D30.A, D32.A, J4.1, JP7.1, R54.1, R63.2, R64.2, R65.2, R66.2, U16.3, U17.GND@0, U17.GND@1, U17.GND@2, U19.GND, U20.2
GND4: C33.2, C34.2, C35.2, C36.2, C37.2, C38.2, C39.C, C40.C, D33.C, D34.C, D36.A, D38.A, D40.A, J5.1, JP9.1, R71.1, R80.2, R81.2, R82.2, R83.2, U21.3, U22.GND@0, U22.GND@1, U22.GND@2, U24.GND, U25.2
GND5: C41.2, C42.2, C43.2, C44.2, C45.2, C46.2, C47.C, C48.C, D41.C, D42.C, D44.A, D46.A, D48.A, J6.1, JP11.1, R88.1, R97.2, R98.2, R99.2, R100.2, U26.3, U27.GND@0, U27.GND@1, U27.GND@2, U29.GND, U30.2
GPS-RX: J1.4, S2.2
GPS-RX1: J2.4, S1.2
GPS-RX2: J3.4, S3.2
GPS-RX3: J4.4, S4.2
GPS-RX4: J5.4, S5.2
GPS-RX5: J6.4, S6.2
GPS-TX: J1.3, S2.5
GPS-TX1: J2.3, S1.5
GPS-TX2: J3.3, S3.5
GPS-TX3: J4.3, S4.5
GPS-TX4: J5.3, S5.5
GPS-TX5: J6.3, S6.5
GRXI: S2.6, U1.D5
GRXI1: S1.6, U7.D5
GRXI2: S3.6, U12.D5
GRXI3: S4.6, U17.D5
GRXI4: S5.6, U22.D5
GRXI5: S6.6, U27.D5
GTXO: S2.3, U1.D4
GTXO1: S1.3, U7.D4
GTXO2: S3.3, U12.D4
GTXO3: S4.3, U17.D4
GTXO4: S5.3, U22.D4
GTXO5: S6.3, U27.D4
HV_SCL: Q2.3, R5.2, U1.A5, U1.SCL
HV_SCL1: Q4.3, R24.2, U7.A5, U7.SCL
HV_SCL2: Q6.3, R41.2, U12.A5, U12.SCL
HV_SCL3: Q8.3, R58.2, U17.A5, U17.SCL
HV_SCL4: Q10.3, R75.2, U22.A5, U22.SCL
HV_SCL5: Q12.3, R92.2, U27.A5, U27.SCL
HV_SDA: Q1.3, R4.2, U1.A4, U1.SDA
HV_SDA1: Q3.3, R22.2, U7.A4, U7.SDA
HV_SDA2: Q5.3, R39.2, U12.A4, U12.SDA
HV_SDA3: Q7.3, R56.2, U17.A4, U17.SDA
HV_SDA4: Q9.3, R73.2, U22.A4, U22.SDA
HV_SDA5: Q11.3, R90.2, U27.A4, U27.SDA
INT-PRESSURE: JP1.2, U4.6
INT-PRESSURE1: JP4.2, U2.6
INT-PRESSURE2: JP6.2, U11.6
INT-PRESSURE3: JP8.2, U16.6
INT-PRESSURE4: JP10.2, U21.6
INT-PRESSURE5: JP12.2, U26.6
LIGHT: R10.2, U1.A1, U3.E
LIGHT1: R20.2, U7.A1, U8.E
LIGHT2: R37.2, U12.A1, U13.E
LIGHT3: R54.2, U17.A1, U18.E
LIGHT4: R71.2, U22.A1, U23.E
LIGHT5: R88.2, U27.A1, U28.E
unnamed: JP10-DNP.3, R14.2
unnamed: JP10-DNP.2, R13.2
unnamed: D1.A, R1.2
unnamed: JP9-DNP.3, R11.2
unnamed: C6.1, U4.2
unnamed: JP1.1, U1.D12
unnamed: D3.A, R6.2
unnamed: D2.A, R18.2
unnamed: D4.A, R19.2
unnamed: C10.1, U2.2
unnamed: JP9-DNP.4, R12.1
unnamed: JP10-DNP.5, R15.1
unnamed: JP10-DNP.4, R16.1
unnamed: JP10-DNP1.2, R28.2
unnamed: JP10-DNP1.3, R26.2
unnamed: JP9-DNP1.3, R27.2
unnamed: JP9-DNP1.4, R29.1
unnamed: JP10-DNP1.5, R30.1
unnamed: JP10-DNP1.4, R31.1
unnamed: JP4.1, U7.D12
unnamed: D17.A, R35.2
unnamed: D18.A, R36.2
unnamed: C20.1, U11.2
unnamed: JP10-DNP2.2, R45.2
unnamed: JP10-DNP2.3, R43.2
unnamed: JP9-DNP2.3, R44.2
unnamed: JP9-DNP2.4, R46.1
unnamed: JP10-DNP2.5, R47.1
unnamed: JP10-DNP2.4, R48.1
unnamed: JP6.1, U12.D12
unnamed: D25.A, R52.2
unnamed: D26.A, R53.2
unnamed: C28.1, U16.2
unnamed: JP10-DNP3.2, R62.2
unnamed: JP10-DNP3.3, R60.2
unnamed: JP9-DNP3.3, R61.2
unnamed: JP9-DNP3.4, R63.1
unnamed: JP10-DNP3.5, R64.1
unnamed: JP10-DNP3.4, R65.1
unnamed: JP8.1, U17.D12
unnamed: D33.A, R69.2
unnamed: D34.A, R70.2
unnamed: C36.1, U21.2
unnamed: JP10-DNP4.2, R79.2
unnamed: JP10-DNP4.3, R77.2
unnamed: JP9-DNP4.3, R78.2
unnamed: JP9-DNP4.4, R80.1
unnamed: JP10-DNP4.5, R81.1
unnamed: JP10-DNP4.4, R82.1
unnamed: JP10.1, U22.D12
unnamed: D41.A, R86.2
unnamed: D42.A, R87.2
unnamed: C44.1, U26.2
unnamed: JP10-DNP5.2, R96.2
unnamed: JP10-DNP5.3, R94.2
unnamed: JP9-DNP5.3, R95.2
unnamed: JP9-DNP5.4, R97.1
unnamed: JP10-DNP5.5, R98.1
unnamed: JP10-DNP5.4, R99.1
unnamed: JP12.1, U27.D12
PWR_CTL: R9.1, U1.D6
PWR_CTL1: R34.1, U7.D6
PWR_CTL2: R51.1, U12.D6
PWR_CTL3: R68.1, U17.D6
PWR_CTL4: R85.1, U22.D6
PWR_CTL5: R102.1, U27.D6
RAIN: D5.A, D6.C, R11.1, U1.D2
RAIN1: D15.A, D16.C, R27.1, U7.D2
RAIN6: D23.A, D24.C, R44.1, U12.D2
RAIN9: D31.A, D32.C, R61.1, U17.D2
RAIN12: D39.A, D40.C, R78.1, U22.D2
RAIN15: D47.A, D48.C, R95.1, U27.D2
RXI: S2.4, U1.RX
RXI1: S1.4, U7.RX
RXI2: S3.4, U12.RX
RXI3: S4.4, U17.RX
RXI4: S5.4, U22.RX
RXI5: S6.4, U27.RX
SCL: Q2.2, R2.2, U4.8, U5.SCK
SCL1: Q4.2, R23.2, U2.8, U9.SCK
SCL2: Q6.2, R40.2, U11.8, U14.SCK
SCL3: Q8.2, R57.2, U16.8, U19.SCK
SCL4: Q10.2, R74.2, U21.8, U24.SCK
SCL5: Q12.2, R91.2, U26.8, U29.SCK
SDA: Q1.2, R3.2, U4.7, U5.DATA
SDA1: Q3.2, R21.2, U2.7, U9.DATA
SDA2: Q5.2, R38.2, U11.7, U14.DATA
SDA3: Q7.2, R55.2, U16.7, U19.DATA
SDA4: Q9.2, R72.2, U21.7, U24.DATA
SDA5: Q11.2, R89.2, U26.7, U29.DATA
STAT1: R1.1, U1.D7
STAT2: R6.1, U1.D8
STAT3: R18.1, U7.D8
STAT4: R19.1, U7.D7
STAT5: R35.1, U12.D8
STAT6: R36.1, U12.D7
STAT7: R52.1, U17.D8
STAT8: R53.1, U17.D7
STAT9: R69.1, U22.D8
STAT10: R70.1, U22.D7
STAT11: R86.1, U27.D8
STAT12: R87.1, U27.D7
TXO: S2.1, U1.TX
TXO1: S1.1, U7.TX
TXO2: S3.1, U12.TX
TXO3: S4.1, U17.TX
TXO4: S5.1, U22.TX
TXO5: S6.1, U27.TX
VIN: C13.A, R8.1, U1.VIN, U6.1, U6.3
VIN1: C15.A, R33.1, U7.VIN, U10.1, U10.3
VIN2: C23.A, R50.1, U12.VIN, U15.1, U15.3
VIN3: C31.A, R67.1, U17.VIN, U20.1, U20.3
VIN4: C39.A, R84.1, U22.VIN, U25.1, U25.3
VIN5: C47.A, R101.1, U27.VIN, U30.1, U30.3
V_BATT: J1.5, JP2.2
V_BATT1: J2.5, JP3.2
V_BATT2: J3.5, JP5.2
V_BATT3: J4.5, JP7.2
V_BATT4: J5.5, JP9.2
V_BATT5: J6.5, JP11.2
WDIR: D7.A, D8.C, R13.1, R17.2, U1.A0
WDIR1: D13.A, D14.C, R25.2, R28.1, U7.A0
WDIR2: D21.A, D22.C, R42.2, R45.1, U12.A0
WDIR3: D29.A, D30.C, R59.2, R62.1, U17.A0
WDIR4: D37.A, D38.C, R76.2, R79.1, U22.A0
WDIR5: D45.A, D46.C, R93.2, R96.1, U27.A0
WSPEED: D9.A, D10.C, R14.1, U1.D3
WSPEED1: D11.A, D12.C, R26.1, U7.D3
WSPEED2: D19.A, D20.C, R43.1, U12.D3
WSPEED3: D27.A, D28.C, R60.1, U17.D3
WSPEED4: D35.A, D36.C, R77.1, U22.D3
WSPEED5: D43.A, D44.C, R94.1, U27.D3

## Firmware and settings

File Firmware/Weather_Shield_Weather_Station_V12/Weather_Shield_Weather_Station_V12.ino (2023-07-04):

/*
  Weather Shield Example
  By: Nathan Seidle
  SparkFun Electronics
  Date: November 16th, 2013
  License: This code is public domain but you buy me a beer if you use this and we meet someday (Beerware license).

  Much of this is based on Mike Grusin's USB Weather Board code: https://www.sparkfun.com/products/10586

  This is a more advanced example of how to utilize every aspect of the weather shield. See the basic
  example if you're just getting started.

  This code reads all the various sensors (wind speed, direction, rain gauge, humidity, pressure, light, batt_lvl)
  and reports it over the serial comm port. This can be easily routed to a datalogger (such as OpenLog) or
  a wireless transmitter (such as Electric Imp).

  Measurements are reported once a second but windspeed and rain gauge are tied to interrupts that are
  calculated at each report.

  This example code assumes the GPS module is not used.

  Updated by Joel Bartlett
  03/02/2017
  Removed HTU21D code and replaced with Si7021

  Updated be Wes Furuya
  06/19/2023
  Implemented "Weather Meter" Arduino library
*/

#include <Wire.h>                                        //I2C needed for sensors
#include "SparkFunMPL3115A2.h"                           //Pressure sensor - Search "SparkFun MPL3115" and install from Library Manager
#include "SparkFun_Si7021_Breakout_Library.h"            //Humidity sensor - Search "SparkFun Si7021" and install from Library Manager
#include "SparkFun_Weather_Meter_Kit_Arduino_Library.h"  //Weather meter kit - Search "SparkFun Weather Meter" and install from Library Manager


//Hardware pin definitions
//-=-=-=-=-=-=-=-=-=-=-=-=-=-=-=-=-=-=-=-=-=-=-=-=-=-=-=-=
// digital I/O pins
const byte WSPEED = 3;
const byte RAIN = 2;
const byte STAT1 = 7;
const byte STAT2 = 8;

// analog I/O pins
const byte REFERENCE_3V3 = A3;
const byte LIGHT = A1;
const byte BATT = A2;
const byte WDIR = A0;
//-=-=-=-=-=-=-=-=-=-=-=-=-=-=-=-=-=-=-=-=-=-=-=-=-=-=-=-=

//Global Variables
//-=-=-=-=-=-=-=-=-=-=-=-=-=-=-=-=-=-=-=-=-=-=-=-=-=-=-=-=
long lastSecond;  //The millis counter to see when a second rolls by

float humidity = 0;  // [%]
float tempf = 0;     // [temperature F]
//float baromin = 30.03;// [barom in] - It's hard to calculate baromin locally, do this in the agent
float pressure = 0;

float wind_dir = 0;    // [degrees (Cardinal)]
float wind_speed = 0;  // [kph]
float rain = 0;        // [mm]

float batt_lvl = 11.8;  //[analog value from 0 to 1023]
float light_lvl = 455;  //[analog value from 0 to 1023]
//-=-=-=-=-=-=-=-=-=-=-=-=-=-=-=-=-=-=-=-=-=-=-=-=-=-=-=-=


MPL3115A2 myPressure;                                      //Create an instance of the pressure sensor
Weather myHumidity;                                        //Create an instance of the humidity sensor
SFEWeatherMeterKit myweatherMeterKit(WDIR, WSPEED, RAIN);  // Create an instance of the weather meter kit


void setup() {
  Serial.begin(115200);
  Serial.println("Weather Shield Example");

  pinMode(STAT1, OUTPUT);  //Status LED Blue
  pinMode(STAT2, OUTPUT);  //Status LED Green

  // pinMode(WSPEED, INPUT_PULLUP); // input from wind meters windspeed sensor
  // pinMode(RAIN, INPUT_PULLUP); // input from wind meters rain gauge sensor

  pinMode(REFERENCE_3V3, INPUT);
  pinMode(LIGHT, INPUT);

  //Configure the pressure sensor
  myPressure.begin();               // Get sensor online
  myPressure.setModeBarometer();    // Measure pressure in Pascals from 20 to 110 kPa
  myPressure.setOversampleRate(7);  // Set Oversample to the recommended 128
  myPressure.enableEventFlags();    // Enable all three pressure and temp event flags

  //Configure the humidity sensor
  myHumidity.begin();

  // The weather meter kit library assumes a 12-bit ADC
  // Configuring a 10-bit ADC resolution for the ATmega328 (RedBoard/Uno)
  myweatherMeterKit.setADCResolutionBits(10);

  // Begin weather meter kit
  myweatherMeterKit.begin();

  lastSecond = millis();

  // // attach external interrupt pins to IRQ functions
  // attachInterrupt(0, rainIRQ, FALLING);
  // attachInterrupt(1, wspeedIRQ, FALLING);

  // // turn on interrupts
  // interrupts();

  Serial.println("Weather Shield online!");
}

void loop() {
  //Keep track of which minute it is
  if (millis() - lastSecond >= 1000) {
    digitalWrite(STAT1, HIGH);  //Blink stat LED

    lastSecond += 1000;

    //Report all readings every second
    printWeather();
  }

  digitalWrite(STAT1, LOW);  //Turn off stat LED

  delay(100);
}

//Calculates each of the variables that wunderground is expecting
void calcWeather() {

  //Calc temp/humidity from Si7021 sensor
  humidity = myHumidity.getRH();
  tempf = myHumidity.readTempF();

  //Weather Meter Kit
  //Calc Wind
  wind_dir = myweatherMeterKit.getWindDirection();
  wind_speed = myweatherMeterKit.getWindSpeed();
  //Calc Rain
  rain = myweatherMeterKit.getTotalRainfall();

  //Calc pressure from MPL3115A2
  pressure = myPressure.readPressure();

  //Calc light level
  light_lvl = get_light_level();

  //Calc battery level
  batt_lvl = get_battery_level();
}

//Returns the voltage of the light sensor based on the 3.3V rail
//This allows us to ignore what VCC might be (an Arduino plugged into USB has VCC of 4.5 to 5.2V)
float get_light_level() {
  float operatingVoltage = analogRead(REFERENCE_3V3);

  float lightSensor = analogRead(LIGHT);

  operatingVoltage = 3.3 / operatingVoltage;  //The reference voltage is 3.3V

  lightSensor = operatingVoltage * lightSensor;

  return (lightSensor);
}

//Returns the voltage of the raw pin based on the 3.3V rail
//This allows us to ignore what VCC might be (an Arduino plugged into USB has VCC of 4.5 to 5.2V)
//Battery level is connected to the RAW pin on Arduino and is fed through two 5% resistors:
//3.9K on the high side (R1), and 1K on the low side (R2)
float get_battery_level() {
  float operatingVoltage = analogRead(REFERENCE_3V3);

  float rawVoltage = analogRead(BATT);

  operatingVoltage = 3.30 / operatingVoltage;  //The reference voltage is 3.3V

  rawVoltage = operatingVoltage * rawVoltage;  //Convert the 0 to 1023 int to actual voltage on BATT pin

  rawVoltage *= 4.90;  //(3.9k+1k)/1k - multiple BATT voltage by the voltage divider to get actual system voltage

  return (rawVoltage);
}


//Prints the various variables directly to the port
//I don't like the way this function is written but Arduino doesn't support floats under sprintf
void printWeather() {
  calcWeather();  //Go calc all the various sensors

  Serial.println();
  Serial.print("humidity=");
  Serial.print(humidity, 1);
  Serial.print(" %RH, tempf=");
  Serial.print(tempf, 1);
  Serial.print(" F, pressure=");
  Serial.print(pressure, 2);
  Serial.print(" Pa, wind direction= ");
  Serial.print(wind_dir, 1);
  Serial.print(" deg, wind speed= ");
  Serial.print(wind_speed, 1);
  Serial.print(" kph, total rain= ");
  Serial.print(rain, 1);
  Serial.print(" mm, batt_lvl=");
  Serial.print(batt_lvl, 2);
  Serial.print(" V, light_lvl=");
  Serial.print(light_lvl, 2);
  Serial.print(",");
  Serial.println("#");
}

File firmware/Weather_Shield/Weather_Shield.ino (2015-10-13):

/*
 Weather Shield Example
 By: Nathan Seidle
 SparkFun Electronics
 Date: November 16th, 2013
 License: This code is public domain but you buy me a beer if you use this and we meet someday (Beerware license).

 Much of this is based on Mike Grusin's USB Weather Board code: https://www.sparkfun.com/products/10586

 This code reads all the various sensors (wind speed, direction, rain gauge, humidty, pressure, light, batt_lvl)
 and reports it over the serial comm port. This can be easily routed to an datalogger (such as OpenLog) or
 a wireless transmitter (such as Electric Imp).

 Measurements are reported once a second but windspeed and rain gauge are tied to interrupts that are
 calcualted at each report.

 This example code assumes the GPS module is not used.

 */

#include <Wire.h> //I2C needed for sensors
#include "SparkFunMPL3115A2.h" //Pressure sensor
#include "SparkFunHTU21D.h" //Humidity sensor

MPL3115A2 myPressure; //Create an instance of the pressure sensor
HTU21D myHumidity; //Create an instance of the humidity sensor

//Hardware pin definitions
//-=-=-=-=-=-=-=-=-=-=-=-=-=-=-=-=-=-=-=-=-=-=-=-=-=-=-=-=
// digital I/O pins
const byte WSPEED = 3;
const byte RAIN = 2;
const byte STAT1 = 7;
const byte STAT2 = 8;

// analog I/O pins
const byte REFERENCE_3V3 = A3;
const byte LIGHT = A1;
const byte BATT = A2;
const byte WDIR = A0;
//-=-=-=-=-=-=-=-=-=-=-=-=-=-=-=-=-=-=-=-=-=-=-=-=-=-=-=-=

//Global Variables
//-=-=-=-=-=-=-=-=-=-=-=-=-=-=-=-=-=-=-=-=-=-=-=-=-=-=-=-=
long lastSecond; //The millis counter to see when a second rolls by
byte seconds; //When it hits 60, increase the current minute
byte seconds_2m; //Keeps track of the "wind speed/dir avg" over last 2 minutes array of data
byte minutes; //Keeps track of where we are in various arrays of data
byte minutes_10m; //Keeps track of where we are in wind gust/dir over last 10 minutes array of data

long lastWindCheck = 0;
volatile long lastWindIRQ = 0;
volatile byte windClicks = 0;

//We need to keep track of the following variables:
//Wind speed/dir each update (no storage)
//Wind gust/dir over the day (no storage)
//Wind speed/dir, avg over 2 minutes (store 1 per second)
//Wind gust/dir over last 10 minutes (store 1 per minute)
//Rain over the past hour (store 1 per minute)
//Total rain over date (store one per day)

byte windspdavg[120]; //120 bytes to keep track of 2 minute average

#define WIND_DIR_AVG_SIZE 120
int winddiravg[WIND_DIR_AVG_SIZE]; //120 ints to keep track of 2 minute average
float windgust_10m[10]; //10 floats to keep track of 10 minute max
int windgustdirection_10m[10]; //10 ints to keep track of 10 minute max
volatile float rainHour[60]; //60 floating numbers to keep track of 60 minutes of rain

//These are all the weather values that wunderground expects:
int winddir = 0; // [0-360 instantaneous wind direction]
float windspeedmph = 0; // [mph instantaneous wind speed]
float windgustmph = 0; // [mph current wind gust, using software specific time period]
int windgustdir = 0; // [0-360 using software specific time period]
float windspdmph_avg2m = 0; // [mph 2 minute average wind speed mph]
int winddir_avg2m = 0; // [0-360 2 minute average wind direction]
float windgustmph_10m = 0; // [mph past 10 minutes wind gust mph ]
int windgustdir_10m = 0; // [0-360 past 10 minutes wind gust direction]
float humidity = 0; // [%]
float tempf = 0; // [temperature F]
float rainin = 0; // [rain inches over the past hour)] -- the accumulated rainfall in the past 60 min
volatile float dailyrainin = 0; // [rain inches so far today in local time]
//float baromin = 30.03;// [barom in] - It's hard to calculate baromin locally, do this in the agent
float pressure = 0;
//float dewptf; // [dewpoint F] - It's hard to calculate dewpoint locally, do this in the agent

float batt_lvl = 11.8; //[analog value from 0 to 1023]
float light_lvl = 455; //[analog value from 0 to 1023]

// volatiles are subject to modification by IRQs
volatile unsigned long raintime, rainlast, raininterval, rain;

//-=-=-=-=-=-=-=-=-=-=-=-=-=-=-=-=-=-=-=-=-=-=-=-=-=-=-=-=

//Interrupt routines (these are called by the hardware interrupts, not by the main code)
//-=-=-=-=-=-=-=-=-=-=-=-=-=-=-=-=-=-=-=-=-=-=-=-=-=-=-=-=
void rainIRQ()
// Count rain gauge bucket tips as they occur
// Activated by the magnet and reed switch in the rain gauge, attached to input D2
{
	raintime = millis(); // grab current time
	raininterval = raintime - rainlast; // calculate interval between this and last event

	if (raininterval > 10) // ignore switch-bounce glitches less than 10mS after initial edge
	{
		dailyrainin += 0.011; //Each dump is 0.011" of water
		rainHour[minutes] += 0.011; //Increase this minute's amount of rain

		rainlast = raintime; // set up for next event
	}
}

void wspeedIRQ()
// Activated by the magnet in the anemometer (2 ticks per rotation), attached to input D3
{
	if (millis() - lastWindIRQ > 10) // Ignore switch-bounce glitches less than 10ms (142MPH max reading) after the reed switch closes
	{
		lastWindIRQ = millis(); //Grab the current time
		windClicks++; //There is 1.492MPH for each click per second.
	}
}


void setup()
{
	Serial.begin(9600);
	Serial.println("Weather Shield Example");

	pinMode(STAT1, OUTPUT); //Status LED Blue
	pinMode(STAT2, OUTPUT); //Status LED Green

	pinMode(WSPEED, INPUT_PULLUP); // input from wind meters windspeed sensor
	pinMode(RAIN, INPUT_PULLUP); // input from wind meters rain gauge sensor

	pinMode(REFERENCE_3V3, INPUT);
	pinMode(LIGHT, INPUT);

	//Configure the pressure sensor
	myPressure.begin(); // Get sensor online
	myPressure.setModeBarometer(); // Measure pressure in Pascals from 20 to 110 kPa
	myPressure.setOversampleRate(7); // Set Oversample to the recommended 128
	myPressure.enableEventFlags(); // Enable all three pressure and temp event flags

	//Configure the humidity sensor
	myHumidity.begin();

	seconds = 0;
	lastSecond = millis();

	// attach external interrupt pins to IRQ functions
	attachInterrupt(0, rainIRQ, FALLING);
	attachInterrupt(1, wspeedIRQ, FALLING);

	// turn on interrupts
	interrupts();

	Serial.println("Weather Shield online!");

}
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

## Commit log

2013-09-20 Initial commit of v10 hardware.
    [Weather Shield.brd, Weather Shield.sch]
2013-09-20 Added analog sense on VIN/Batt level.
    [Weather Shield.brd, Weather Shield.sch]
2013-09-20 Reduction of ground plane around sensors.
    [Weather Shield.brd]
2013-09-20 Small silk changes.
    [Weather Shield.brd]
2013-09-22 Added power ctl to GPS and backup battery connection.
    [Weather Shield.brd, Weather Shield.sch]
2013-09-22 Tweaked schematic labels and connector for backup battery.
    [Weather Shield.brd, Weather Shield.sch]
2013-09-22 Added support for smaller, cheaper ALS-PT19 light sensor.
    [Weather Shield.brd, Weather Shield.sch]
2013-10-14 v1.1 that addresses many issues.
    Many schematic and routing changes. See issues.
    [Weather Shield.brd, Weather Shield.sch]
2013-10-14 Added milling slots and updated readme.
    Added slots to allow better airflow around sensors.
    [Weather Shield.brd]
2013-10-14 Panel Created
    [Weather Shield-Panel-v11.brd]
2013-11-16 Small cleanup of schematic.
    [Weather Shield.sch]
2015-02-12 Bug call getWindSpeed twice get Nan result
    [Weather_Shield.ino]
2015-09-11 Fixed NaN bug. See bug 15.
    [Weather_Shield.ino]
2015-10-13 Fixing library include statements, updating README, fixing directory structure
    [Weather Shield-Panel-v11.brd]
2016-06-10 Small bug fix to NaN error.
    [Weather_Shield_Weather_Station.ino, Weather_Shield_with_GPS.ino]
2016-08-12 Fixing output to serial monitor for longitude
    changed line 445 to Serial.print(",lng="); to fix this issue:
    https://github.com/sparkfun/Weather_Shield/issues/23
    [Weather_Shield_with_GPS.ino]
2016-08-12 Fixing output for windspeedmph
    Adding line of code at 178:
    windspeedmph = currentSpeed;//update global variable for windspeed when using the printWeather() function
    and added comment to line 227 to explain why the calculation was commented out:
    //windspeedmph = get_wind_speed(); //This is calculated in the main loop on line 179
    to fix this issue => https://github.com/sparkfun/Weather_Shield/issues/24
    [Weather_Shield_Weather_Station.ino]
2016-08-18 V1.2 Initial Checklist pushes
    [Weather Shield_V12.brd, Weather Shield_V12.sch]
2016-08-24 Fixed 4-way junctions
    Fixed 4-way junctions
    [Weather Shield_V12.brd, Weather Shield_V12.sch]
2016-08-25 Post group review changes
    [Weather Shield_V12.brd, Weather Shield_V12.sch]
2016-09-27 Post QC Checklist fixes
    Addressed the few issues that came up during the preliminary QC
    checklist. Mostly PROD_IDs missing and aesthetic fixes.
    [Weather Shield_V12.brd, Weather Shield_V12.sch]
2016-10-24 Removed hard-coded error numbers. Updated ignore to avoid lock files.
    [Weather_Shield_Basic.ino]
2016-11-01 Updated Si7021 footprint
    Updated Si7021 footprint with correct center paste paste.
    [Weather Shield_V12.brd, Weather Shield_V12.sch]
2016-11-08 Pushing fixes to Si7021 IC footprint tSTOP
    [Weather Shield_V12.brd, Weather Shield_V12.sch]
2016-11-30 Slight modifications before final review
    Moved logos to avoid cover up by GPS. Moved GPS backup batter
    connection. Change jumper on D12 to NO instead of NC.
    [Weather Shield.sch, Weather Shield_V12.brd, Weather Shield_V12.sch]
2016-11-30 Moved logo
    [Weather Shield_V12.brd]
2016-12-01 Minor Changes after group review for Reds
    Fixed text under VREG to have correct info, fixed Eagle error on J1
    (GPS Conn), fixed overlapping values, minor silk changes, moved via,
    updated HW/SW serial switch text to modern standard .
    [Weather Shield_V12.brd, Weather Shield_V12.sch]
2016-12-09 Final issue fixes before going out for reds.
    [Weather Shield_V12.brd, Weather Shield_V12.sch]
2017-03-02 Small fix to GPS example
    [Weather_Shield_with_GPS_V12.ino]
2017-06-22 Fix issue w/ windspeedmph in Weather Shield w/ GPS
    I fixed the issue with the _windspeedmph_ in the _Weather_Shield_Weather_Station.ino_ example code [ [https://github.com/sparkfun/Weather_Shield/pull/25](https://github.com/sparkfun/Weather_Shield/pull/25) ]. However, this was also an issue with the _Weather_Shield_with_GPS.ino_ .
    [Weather_Shield_with_GPS.ino]
2018-11-03 Update readme to point to newer Si7021 humidity sensor lib
2019-02-18 Update README.md
    -update image for latest board
    -update sku
2019-02-18 Fix Minor Issues
    -Fix output for windspeedmph related to this issue that was not updated in this version of code [ [https://github.com/sparkfun/Weather_Shield/commit/cb2b3dee3dc1f11ecff50dbc76434f29dbfc3372](https://github.com/sparkfun/Weather_Shield/commit/cb2b3dee3dc1f11ecff50dbc76434f29dbfc3372) ]
    - Fixing output to serial monitor for longitude that was not updated in this version of code [ [https://github.com/sparkfun/Weather_Shield/commit/d09a0d830e3668e70adf77a1f900ca0f23c9663b](https://github.com/sparkfun/Weather_Shield/commit/d09a0d830e3668e70adf77a1f900ca0f23c9663b) ]
    [Weather_Shield_Weather_Station_V12.ino, Weather_Shield_with_GPS_V12.ino]
2019-02-18 Minor Update Path Name
    -Change folder name to Capital letters for firmware and hardware
    [Weather Shield_V12.brd, Weather Shield_V12.sch]
2019-02-18 Removing Duplicate Paths
    [Weather Shield_V12.brd, Weather Shield_V12.sch]
2019-02-18 Re-add Folders
    Re-add examples and hardware folder
    [Weather Shield_V12.brd, Weather Shield_V12.sch]
2019-02-18 Autoformat
    Code was not rending properly online, using the autoformat in Arduino for better viewing.
2023-07-04 Update Code
    Modified code to utilize new "Weather Meter Kit" Arduino library
    Included small updates for the "TinyGPSPlus" Arduino library
    Reconfigured baud rate to 115200bps

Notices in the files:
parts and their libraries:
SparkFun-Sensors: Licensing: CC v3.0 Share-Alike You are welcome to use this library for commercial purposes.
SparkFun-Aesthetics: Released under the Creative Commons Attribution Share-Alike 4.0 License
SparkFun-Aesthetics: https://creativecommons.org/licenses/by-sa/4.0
